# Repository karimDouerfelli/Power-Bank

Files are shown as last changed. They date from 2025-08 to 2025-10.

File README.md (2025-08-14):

the english version is after 

# 🔋 Powerbank 10 000 mAh – Guide Complet PCB (Version 2 × Cellules 1S)

## 1. 📖 L’histoire

On veut fabriquer une **batterie externe** qui :

* Se recharge en USB-C
* Peut charger un téléphone vite (QC/PD)
* A une capacité \~**10 000 mAh**
* Utilise **2 cellules 1S** (en parallèle = 1S2P)

---

## 2. 🧠 Comment ça marche

Imagine deux bouteilles d’eau identiques (les **cellules**).
Si on les relie en parallèle, c’est comme verser dans une grande bassine : plus de capacité mais **même tension**.
Ensuite, un **cerveau électronique** (le BMS et le chip de gestion USB) contrôle :

* **La charge** (ne pas dépasser la tension max)
* **La décharge** (ne pas descendre trop bas)
* **La température** (ne pas chauffer)

---

## 3. 📦 Les ingrédients (BOM principale)

| Nom du composant | Rôle | Référence conseillée |
| --- | --- | --- |
| **Contrôleur USB-C tout-en-un** | Gérer charge/décharge USB, QC, PD | IP5328P |
| **BMS 1S** | Protéger la batterie (surcharge, court-circuit, sous-tension) | DW01A + FS8205A |
| **MOSFETs** | Couper ou autoriser le courant | FS8205A (dans le BMS) |
| **Cellules Li-ion** | Source d’énergie | 2× Samsung INR21700-50E (5000 mAh) |
| **NTC 10 kΩ** | Mesurer température | 103AT-2 |
| **PTC (Polyfuse)** | Protection contre surcourant | RUE600-0.5 |
| **Condensateurs céramiques** | Lisser le courant | 10 µF et 22 µF X5R/X7R |
| **Résistances de détection** | Mesurer courant/tension | Shunt 10–20 mΩ |
| **Connecteur USB-C** | Entrée/sortie énergie | Type-C réversible |
| **PCB 4 couches** | Support et connexions | 100×60 mm, 1 oz cuivre |

---

## 4. 🛠 Schéma de principe

```
[Cellule 1]---+
              |---(Pont de mise en parallèle)---[VBAT]---[BMS 1S]---[IP5328P]---USB-C
[Cellule 2]---+

[NTC] -> vers IP5328P
[PTC] -> sur ligne VBAT après les cellules
```

* **Cellule 1** et **Cellule 2** sont reliées **en parallèle** via un pont (peut être un jumper ou une résistance d’équilibrage temporaire).
* **VBAT** = point où la tension batterie arrive sur le PCB.
* **BMS 1S** placé **avant** le contrôleur USB pour protéger la batterie.

---

## 5. 🎨 Design du PCB (4 couches)

**Couche 1 (Top)**

* Composants principaux (IP5328P, BMS, USB-C)
* Pistes de signal
* Zones de cuivre pour le **+BAT** et **GND**
* Largeur piste batterie : ≥ 2 mm (pour 3–5 A)

**Couche 2 (GND)**

* Plan de masse complet (GND)
* Connexions directes aux pads GND des composants

**Couche 3 (VBAT)**

* Plan entier pour le +BAT (après BMS)
* Évite pertes et échauffement

**Couche 4 (Bottom)**

* Composants secondaires (résistances, petits condos)
* Pads pour test (VBAT\_A, VBAT\_B, VBAT\_SUM)
* Pont de mise en parallèle (empreinte de résistance/jumper)

---

## 6. 🧩 Étapes de routage

1. **Commencer par le connecteur USB-C**

   * Traces différentielles pour CC1/CC2 si besoin
   * Pistes larges pour VBUS et GND
2. **Placer l’IP5328P** proche du port USB-C

   * Condensateurs d’entrée/sortie **le plus près possible**
3. **BMS 1S** proche des pads BAT+ / BAT-

   * MOSFETs orientés pour flux direct vers IP5328P
4. **Plans de cuivre** :

   * GND sur Couche 2
   * VBAT sur Couche 3
5. **Pads séparés pour Cellule 1 et Cellule 2**

   * Permet test individuel avant soudure
6. **Pont de mise en parallèle** :

   * Footprint d’une résistance 1206 (0.5–1 Ω)
   * Remplacée par un shunt une fois équilibré
7. **NTC** :

   * Empreinte pour connecteur JST ou soudage direct
   * Placer piste fine vers IP5328P

---

## 7. 🔌 Connexions importantes

* **VBAT\_A** et **VBAT\_B** : chaque cellule séparée
* **Pont parallèle** : à fermer après équilibrage
* **PTC** : en série sur VBAT pour protection
* **NTC** : collée sur cellule et reliée au contrôleur
* **Shunt courant** : entre BMS et IP5328P

---

## 8. 📐 Règles de fabrication PCB

* **Épaisseur cuivre** : 1 oz (35 µm)
* **Largeur piste puissance** : ≥ 2 mm pour >3 A
* **Via stitching** sur zones VBAT et GND
* **Minimum clearance** : 0.2 mm
* **Sérigraphie** claire (polarités, repères tests)

---

## 9. 📋 Procédure d’assemblage

1. Souder tous les composants CMS du PCB
2. Fixer connecteur USB-C
3. Relier cellules **sans** fermer le pont parallèle
4. Mesurer tension des deux cellules

   * Si écart ≤ 0.05 V → fermer pont (shunt)
5. Fixer NTC sur cellule
6. Brancher batterie et tester charge/décharge
7. Si tout OK → fermer boîtier

---

## 10. 💰 Coût estimatif

| Élément | Prix (\~€) |
| --- | --- |
| IP5328P | 0.90 |
| BMS 1S | 0.40 |
| MOSFETs supplémentaires  | 0.20 |
| USB-C | 0.30 |
| Passifs (résistances, C) | 1.50 |
| PCB 4 couches | 3.00 |
| Cellules Li-ion | 6.90 |
| **Total** | **\~16.8** |

---

## 11. ⚠ Conseils sécurité

* Ne jamais court-circuiter une cellule
* Toujours vérifier température lors des premiers cycles
* Utiliser uniquement cellules en bon état et identiques

---

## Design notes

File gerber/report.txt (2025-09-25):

Plotted to '/home/karim/power_bank/gerber/power_bank-F_Cu.gbr'.
Plotted to '/home/karim/power_bank/gerber/power_bank-In1_Cu.gbr'.
Plotted to '/home/karim/power_bank/gerber/power_bank-In2_Cu.gbr'.
Plotted to '/home/karim/power_bank/gerber/power_bank-B_Cu.gbr'.
Plotted to '/home/karim/power_bank/gerber/power_bank-F_Paste.gbr'.
Plotted to '/home/karim/power_bank/gerber/power_bank-B_Paste.gbr'.
Plotted to '/home/karim/power_bank/gerber/power_bank-F_Silkscreen.gbr'.
Plotted to '/home/karim/power_bank/gerber/power_bank-B_Silkscreen.gbr'.
Plotted to '/home/karim/power_bank/gerber/power_bank-F_Mask.gbr'.
Plotted to '/home/karim/power_bank/gerber/power_bank-B_Mask.gbr'.
Plotted to '/home/karim/power_bank/gerber/power_bank-Edge_Cuts.gbr'.
Created Gerber job file '/home/karim/power_bank/gerber/power_bank-job.gbrjob'.
Info: Done.
Info: Done.

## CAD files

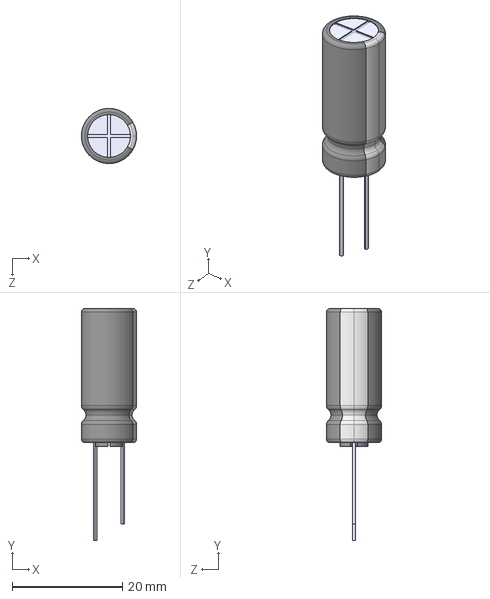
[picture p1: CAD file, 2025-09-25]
EEUFS1K221LB/EEUFS1K221LB.step
10.0 x 42.0 x 9.99 mm

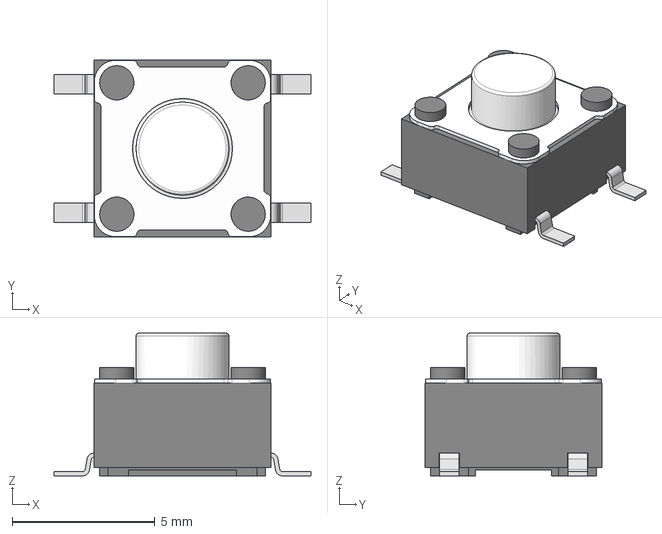
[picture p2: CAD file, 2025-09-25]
430152050826/430152050826.step
9.00 x 6.20 x 5.00 mm

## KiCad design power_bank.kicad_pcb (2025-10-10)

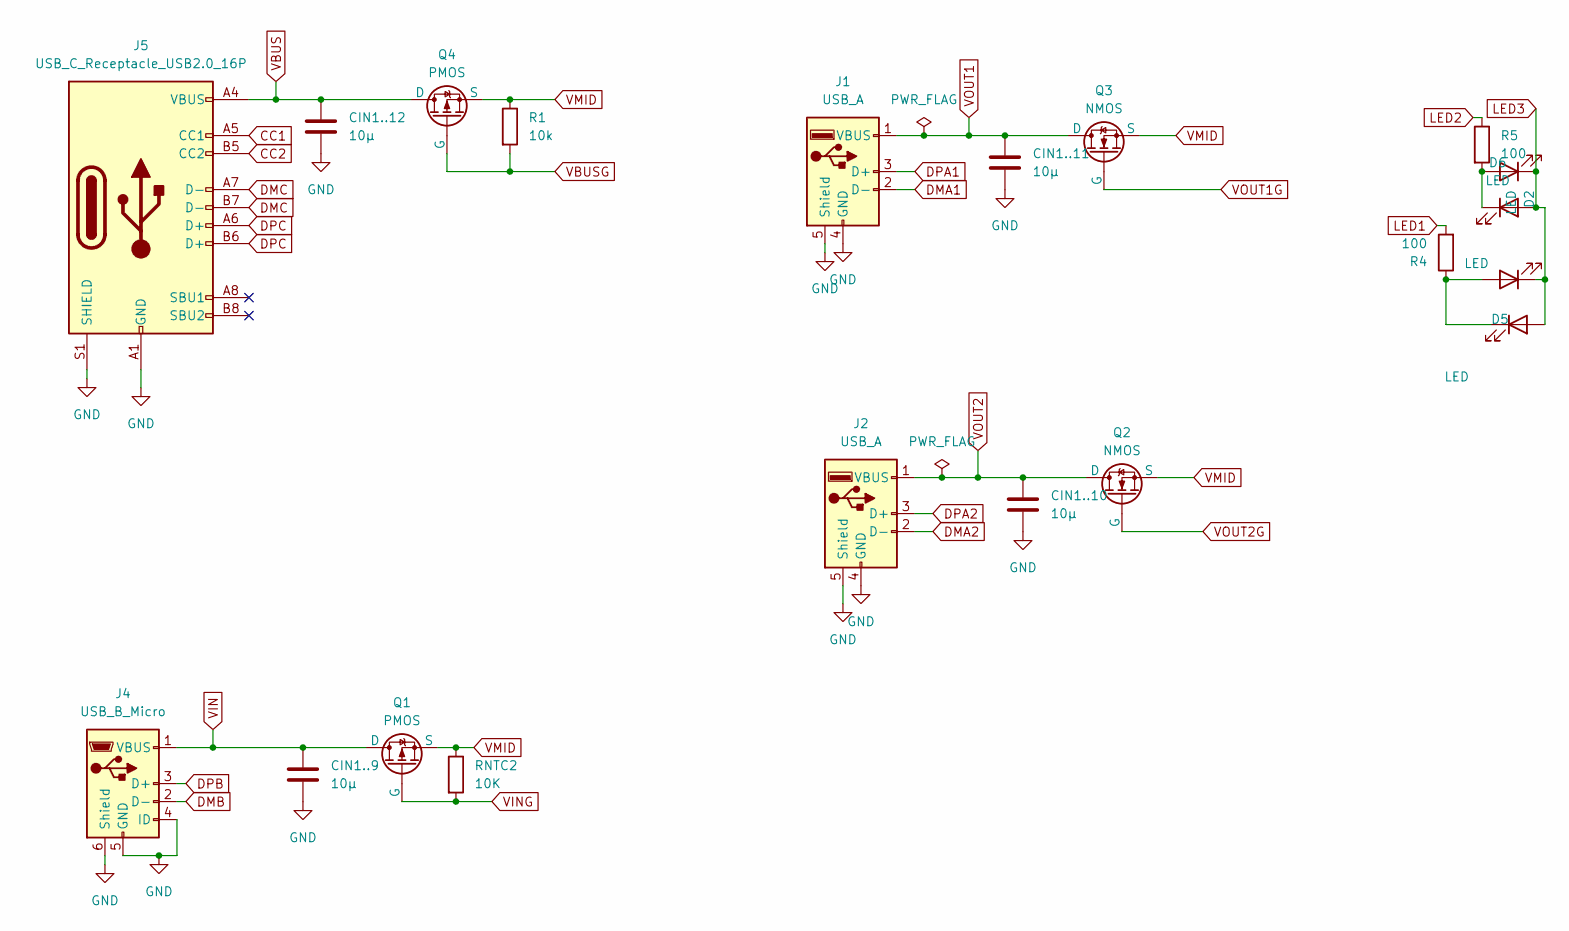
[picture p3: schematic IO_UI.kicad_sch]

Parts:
CIN1..9, CIN1..10, CIN1..11, CIN1..12: 10µ; C_0805_2012Metric
D1, D2, D5, D6: LED; LED_0603_1608Metric
J1, J2: USB_A; USB_A_CNCTech_1001-011-01101_Horizontal
J4: USB_B_Micro; USB_Micro-B_Wuerth_629105150521
J5: USB_C_Receptacle_USB2.0_16P; USB_C_Receptacle_HCTL_HC-TYPE-C-16P-01A
Q1, Q4: PMOS; TSOT-23
Q2, Q3: NMOS; TSOT-23
R1: 10k; R_0603_1608Metric
R4, R5: 100; R_0603_1608Metric
RNTC2: 10K; R_0603_1608Metric

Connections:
CC1: J5.A5 (CC1); also elsewhere on the board
CC2: J5.B5 (CC2); also elsewhere on the board
DMA1: J1.2 (D-); also elsewhere on the board
DMA2: J2.2 (D-); also elsewhere on the board
DMB: J4.2 (D-); also elsewhere on the board
DMC: J5.A7 (D-), J5.B7 (D-); also elsewhere on the board
DPA1: J1.3 (D+); also elsewhere on the board
DPA2: J2.3 (D+); also elsewhere on the board
DPB: J4.3 (D+); also elsewhere on the board
DPC: J5.A6 (D+), J5.B6 (D+); also elsewhere on the board
GND: CIN1..9.2, CIN1..10.2, CIN1..11.2, CIN1..12.2, J1.4 (GND), J1.5 (Shield), J2.4 (GND), J2.5 (Shield), J4.4 (ID), J4.5 (GND), J4.6 (Shield), J5.A1 (GND), J5.A12 (GND), J5.B1 (GND), J5.B12 (GND), J5.S1 (SHIELD); also elsewhere on the board
LED1: R4.2; also elsewhere on the board
LED2: R5.1; also elsewhere on the board
LED3: D1.1 (K), D2.1 (K), D5.2 (A), D6.2 (A); also elsewhere on the board
unnamed: D1.2 (A), D5.1 (K), R4.1
unnamed: D2.2 (A), D6.1 (K), R5.2
VBUS: CIN1..12.1, J5.A4 (VBUS), J5.A9 (VBUS), J5.B4 (VBUS), J5.B9 (VBUS), Q4.1 (D); also elsewhere on the board
VBUSG: Q4.2 (G), R1.2; also elsewhere on the board
VIN: CIN1..9.1, J4.1 (VBUS), Q1.1 (D); also elsewhere on the board
VING: Q1.2 (G), RNTC2.2; also elsewhere on the board
VMID: Q1.3 (S), Q2.3 (S), Q3.3 (S), Q4.3 (S), R1.1, RNTC2.1; also elsewhere on the board
VOUT1: CIN1..11.1, J1.1 (VBUS), Q3.1 (D); also elsewhere on the board
VOUT1G: Q3.2 (G); also elsewhere on the board
VOUT2: CIN1..10.1, J2.1 (VBUS), Q2.1 (D); also elsewhere on the board
VOUT2G: Q2.2 (G); also elsewhere on the board

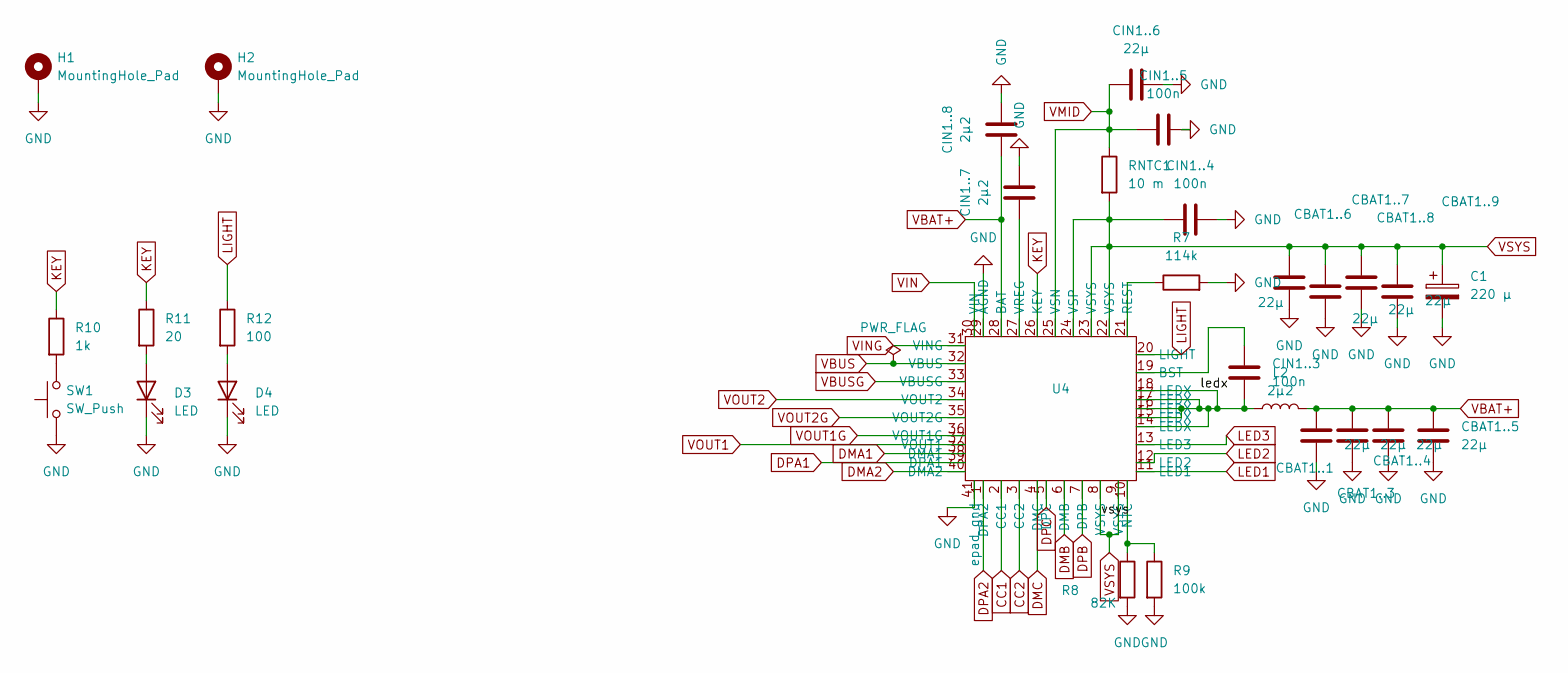
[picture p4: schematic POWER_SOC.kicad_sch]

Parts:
C1: 220 µ; CAPPRD500W60D1000H2500
CBAT1..1, CBAT1..3, CBAT1..4, CBAT1..5, CBAT1..6, CBAT1..7, CBAT1..8, CBAT1..9: 22µ; C_0805_2012Metric
CIN1..3, CIN1..4, CIN1..5: 100n; C_0603_1608Metric
CIN1..6: 22µ; C_0805_2012Metric
CIN1..7, CIN1..8: 2µ2; C_0603_1608Metric
D3: LED; LED_D3.0mm
D4: LED; LED_0603_1608Metric
H1, H2: MountingHole_Pad; MountingHole_2.2mm_M2_DIN965_Pad
L2: 2µ2; L_10.4x10.4_H4.8
R7: 114k; R_0603_1608Metric
R8: 82K; R_0603_1608Metric
R9: 100k; R_0603_1608Metric
R10: 1k; R_0603_1608Metric
R11: 20; R_0603_1608Metric
R12: 100; R_0603_1608Metric
RNTC1: 10 m; R_1206_3216Metric
SW1: SW_Push; SW_DIP_SPSTx01_Slide_6.7x4.1mm_W6.73mm_P2.54mm_LowProfile_J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
U4: QFN-40-1EP_6x6mm_P0.5mm_EP4.6x4.6mm

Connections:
/POWER_SOC/ledx: CIN1..3.1, L2.1, U4.14 (LEDX), U4.15 (LEDX), U4.16 (LEDX), U4.17 (LEDX), U4.18 (LEDX)
CC1: U4.2 (CC1); also elsewhere on the board
CC2: U4.3 (CC2); also elsewhere on the board
DMA1: U4.38 (DMA1); also elsewhere on the board
DMA2: U4.40 (DMA2); also elsewhere on the board
DMB: U4.6 (DMB); also elsewhere on the board
DMC: U4.4 (DMC); also elsewhere on the board
DPA1: U4.39 (DPA1); also elsewhere on the board
DPA2: U4.1 (DPA2); also elsewhere on the board
DPB: U4.7 (DPB); also elsewhere on the board
DPC: U4.5 (DPC); also elsewhere on the board
GND: C1.2, CBAT1..1.2, CBAT1..3.2, CBAT1..4.2, CBAT1..5.2, CBAT1..6.2, CBAT1..7.2, CBAT1..8.2, CBAT1..9.2, CIN1..4.1, CIN1..5.1, CIN1..6.1, CIN1..7.1, CIN1..8.1, D3.1 (K), D4.1 (K), H1.1, H2.1, R7.2, R8.2, R9.2, SW1.1, U4.29 (AGND), U4.41 (epad_gnd); also elsewhere on the board
KEY: R10.1, R11.1, U4.26 (KEY)
LED1: U4.11 (LED1); also elsewhere on the board
LED2: U4.12 (LED2); also elsewhere on the board
LED3: U4.13 (LED3); also elsewhere on the board
LIGHT: R12.1, U4.20 (LIGHT)
unnamed: D3.2 (A), R11.2
unnamed: D4.2 (A), R12.2
unnamed: R10.2, SW1.2
unnamed: CIN1..3.2, U4.19 (BST)
unnamed: R8.1, R9.1, U4.10 (NTC)
unnamed: R7.1, U4.21 (REST)
unnamed: CIN1..7.2, U4.27 (VREG)
VBAT+: CBAT1..1.1, CBAT1..3.1, CBAT1..4.1, CBAT1..5.1, CIN1..8.2, L2.2, U4.28 (BAT)
VBUS: U4.32 (VBUS); also elsewhere on the board
VBUSG: U4.33 (VBUSG); also elsewhere on the board
VIN: U4.30 (VIN); also elsewhere on the board
VING: U4.31 (VING); also elsewhere on the board
VMID: CIN1..5.2, CIN1..6.2, RNTC1.1, U4.25 (VSN); also elsewhere on the board
VOUT1: U4.37 (VOUT1); also elsewhere on the board
VOUT1G: U4.36 (VOUT1G); also elsewhere on the board
VOUT2: U4.34 (VOUT2); also elsewhere on the board
VOUT2G: U4.35 (VOUT2G); also elsewhere on the board
VSYS: C1.1, CBAT1..6.1, CBAT1..7.1, CBAT1..8.1, CBAT1..9.1, CIN1..4.2, RNTC1.2, U4.8 (VSYS), U4.9 (VSYS), U4.22 (VSYS), U4.23 (VSYS), U4.24 (VSP)

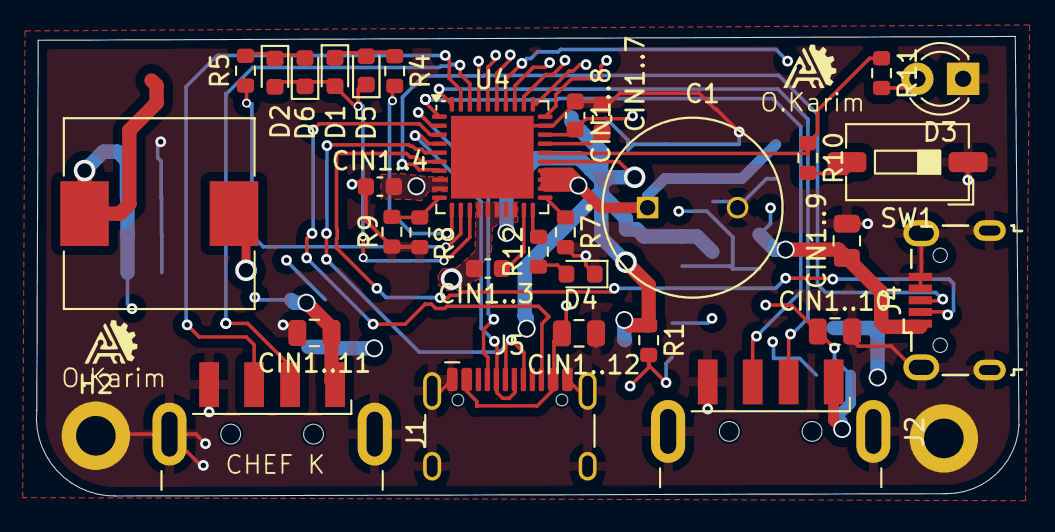
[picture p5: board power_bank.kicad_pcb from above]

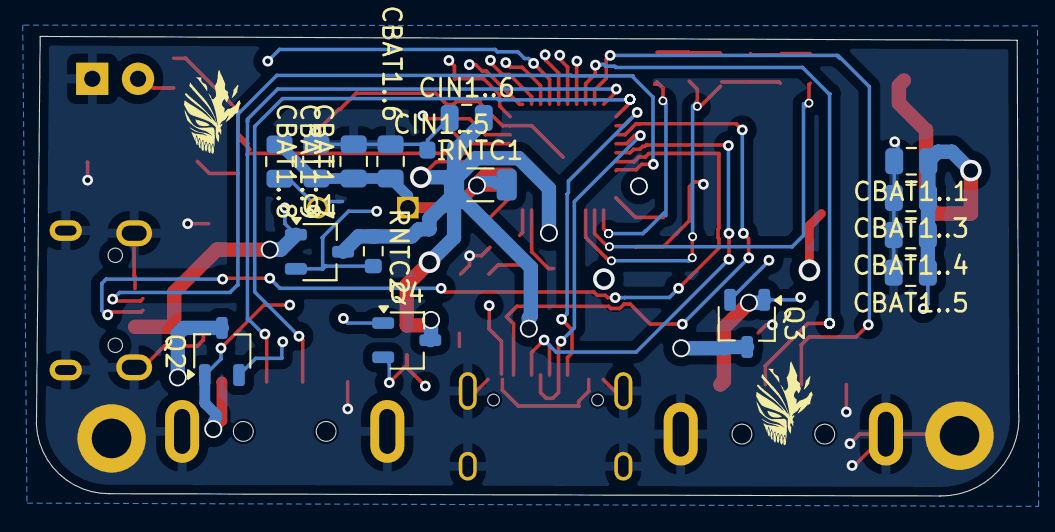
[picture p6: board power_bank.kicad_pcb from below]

Board: 4 copper layers, 54.6 x 25.5 mm, 49 parts (16 on the bottom side), 37 nets.

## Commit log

2025-09-25 Premier commit
    [430152050826.step, EEUFS1K221LB.step, IO_UI.kicad_sch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]
2025-10-10 gerber command
    [IO_UI.kicad_sch, POWER_SOC.kicad_sch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]
